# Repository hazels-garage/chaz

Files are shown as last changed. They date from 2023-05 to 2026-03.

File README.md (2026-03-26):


<a href="https://discord.gg/jP6hvgNN8r">
  
</a>

# Chaz

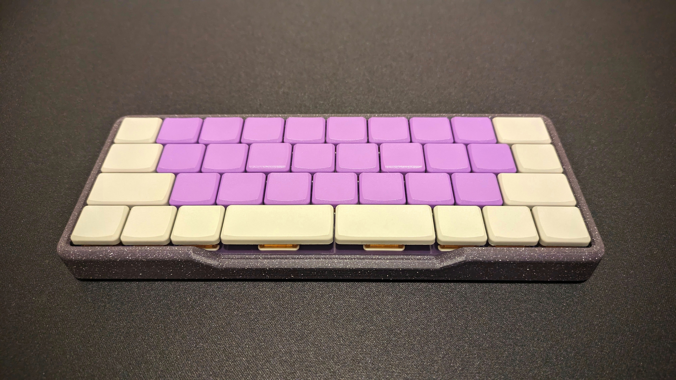
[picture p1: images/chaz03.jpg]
Chaz

Low Profile, Choc Spaced QAZ-alike

## Features
* QAZ Layout
* Choc Spaced
* Integrated STM32F702 microcontroller
* [Open Source](/source)

## Materials
* 1x Chaz PCB & Switchplate - [Buy](https://shop.hazel.cc/products/chaz-v03) - [Source](/source)
* 2x 2U Kailh Choc Stabalizers
* 37x Kailh Choc v1 Switches
* 37x Keycaps
  * 31x 1u 
  * 2x 1.25u
  * 1x 1.75u
  * 1x 1.5u
  * 1x 2u
  * 1x 2.25u
* 1x [Case](case/)
* 6x M2x6 countersunk screws  

## Build Steps
* Insert switches into switchplate
  * **NOTE**: There are 3 switches rotated differently from the rest.  Check the PCB to make sure you've got the correct orientation
* [Insert stabalizers](https://docs.keeb.io/choc-stabs)
* Place switchplate with switches onto PCB and press all the switches into their homes.
* Solder Switches
* Insert into case
* Screw Case to PCB from the bottom

## Firmware
To get into DFU, hold the DFU button on the bottom of the PCB while plugging in USB.

* [QMK](https://github.com/hazels-garage/qmk_firmware/tree/hazel/chaz)
* [VIAL](firmware/hazel_chaz_v03_vial.bin)
* [ZMK](https://github.com/hazels-garage/zmk-chaz)

## Changelog
* v0.3 - Current STM32F072CBT6 
* v0.2 - Unreleased and Unverified RP2040 
* v0.1 - Previously released ProMicro 
* v0.0 - Unreleased, but Verified ProMicro 

## Credits
* tominabox1 and whydobearsxplod for the original QAZ
* sporkus for [Le Chiffre STM32](https://github.com/sporkus/le_chiffre_keyboard_stm32) that I used as reference.
* [Pete Johanson](https://github.com/petejohanson) for suggesting I try STM32F072CBT6

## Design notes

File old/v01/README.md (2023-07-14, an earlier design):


<a href="https://shop.hazel.cc/products/chaz">
 </a>
<a href="https://discord.gg/jP6hvgNN8r">
  
</a>

# Chaz
Low profile, choc spaced QAZ-alike

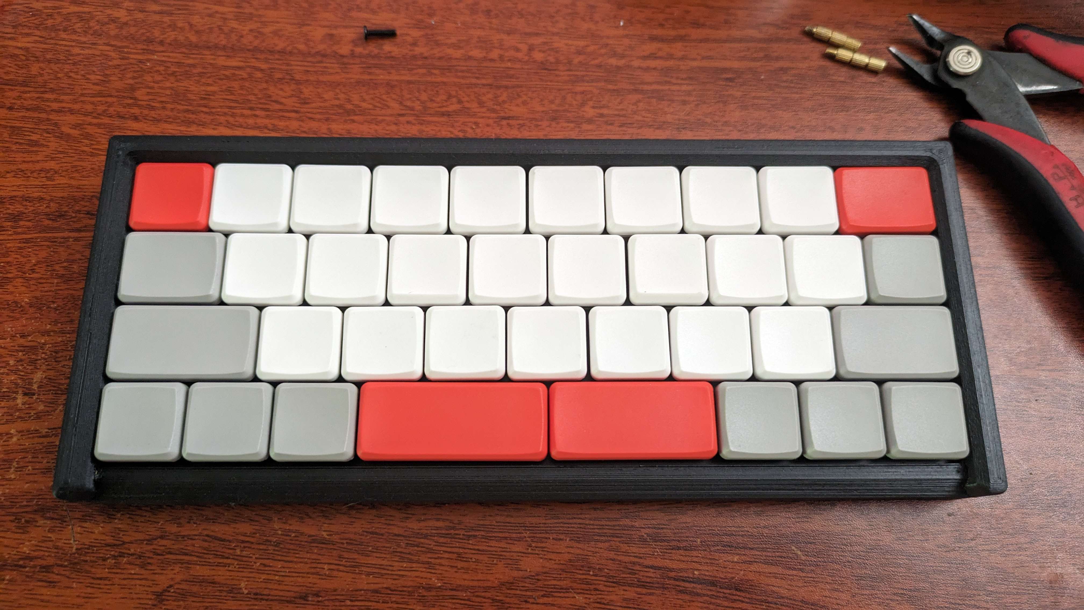
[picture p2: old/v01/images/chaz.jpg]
Chaz


# Features
* QAZ Layout
* Choc Spaced
* ProMicro Style Controllers
* Battery support
* [Open Source](source/)

# Materials
* 1x ProMicro Compatible Controller
* 1x [PH3.5 12P Socket](https://www.aliexpress.us/item/2251800435894905.html)
* 1x [PH3.5 7P Socket](https://www.aliexpress.us/item/2251800435894905.html)
* 37x Kailh Choc v1 switches
* 37x Keycaps
  * 31x 1u 
  * 2x 1.25u
  * 1x 1.75u
  * 1x 1.5u
  * 1x 2u
  * 1x 2.25u
* 37x SOD-123 1N4148 Diodes
* 1x [SKHLLCA010 Reset Button](https://www.aliexpress.us/item/3256804101901854.html)
* 1x [OS10201MA1QN1 Power Switch](https://www.digikey.com/en/products/detail/c-k/OS102011MA1QN1/1981430)  (optional)
* 2x [Kailh Choc 2u Stabalizers](https://www.aliexpress.us/item/2251832852867988.html)
* 4x 9mm M2 Standoffs
* 8x 4mm M2 Screws

# Build Guide
* Solder Diodes
* Solder Controller Headers
* Solder Reset Switch
* Solder Power Switch and Battery (Optional)
* Install Controller
* Flash [Firmware](FIRMWARE.md)
* Test matrix works 
  * use metal tweezers to short the connections for each switch on the PCB
* Insert Switches and Stabalizers into Switchplate
* Solder Switches to PCB (remove controller first)
* Attach Backplate to Switchplate with Standoffs and screws
* Done.

# Case Build Guide
* Print [Case](case/case.stl)
* Install 4x heatset inserts.
* secure switchplate to heatset inserts with Male/Female Brass Standoff
* 8mm-ish screw through Backplate into Brass Standoff

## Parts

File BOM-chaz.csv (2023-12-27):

Comment | Designator | Footprint | LCSC
DFU | BOOT0 | SW_SPST_TL3342 | C115351
4.7n | C_Shield1 | C_0402_1005Metric | C1538
10uF | C8 | C_0603_1608Metric | C19702
USB_C | J1 | Molex-216990_GCT-USB45xx_HRO-TYPE-C-31-M-13x | C223906
27R | R3,R4 | R_0603_1608Metric | C25190
10k | R5 | R_0402_1005Metric | C25744
5.1k | R1,R2 | R_0402_1005Metric | C25905
1M | R_Shield1 | R_0402_1005Metric | C26083
MountingHole | H1,H2,H3,H4,H5,H6 | MountingHole_M2_Pad_NonPTH_TopOnly | C2916384
100nF | C3,C4,C5,C6,C7,C9 | C_0402_1005Metric | C307331
1uF | C1,C2 | C_0402_1005Metric | C52923
XC6206 | U3 | SOT-23 | C5446
500mA | F1 | Fuse_1206_3216Metric | C70076
1N4148W | D1,D10,D11,D12,D13,D14,D15,D16,D17,D18,D19,D2,D20,D21,D22,D23,D24,D25,D26,D27,D28,D29,D3,D30,D31,D32,D33,D34,D35,D36,D37,D4,D5,D6,D7,D8,D9 | D_SOD-123 | C81598
STM32F072CBT6 | U1 | LQFP-48_7x7mm_P0.5mm | C81720
SRV05-4 | U2 | SOT-23-6-routable | C85364

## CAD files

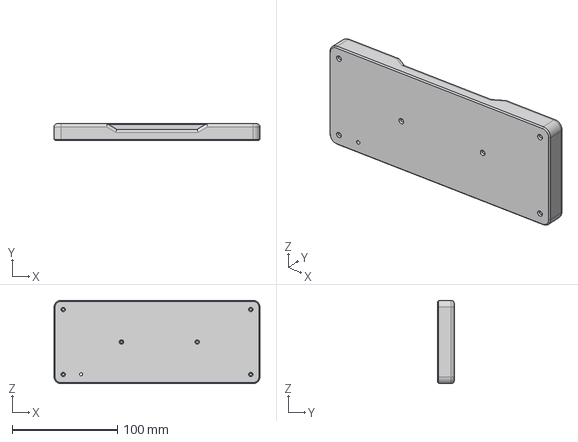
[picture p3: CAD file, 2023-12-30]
case/chaz-case.step
195.5 x 15.8 x 79.0 mm

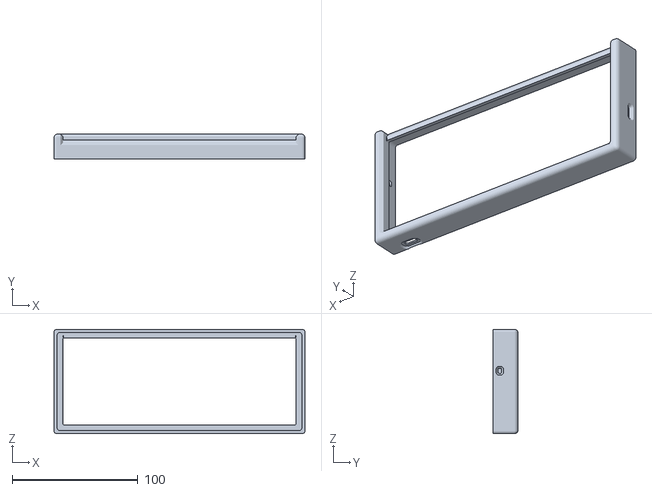
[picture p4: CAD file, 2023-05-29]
case/case.stl
199.5 x 20.0 x 83.0

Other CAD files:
case/chaz-case.3mf

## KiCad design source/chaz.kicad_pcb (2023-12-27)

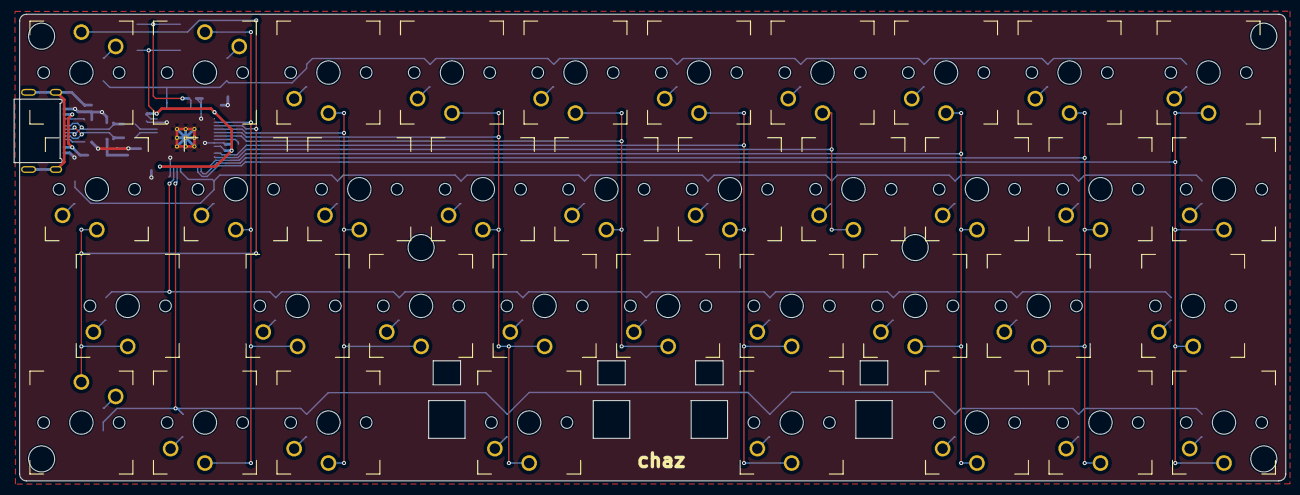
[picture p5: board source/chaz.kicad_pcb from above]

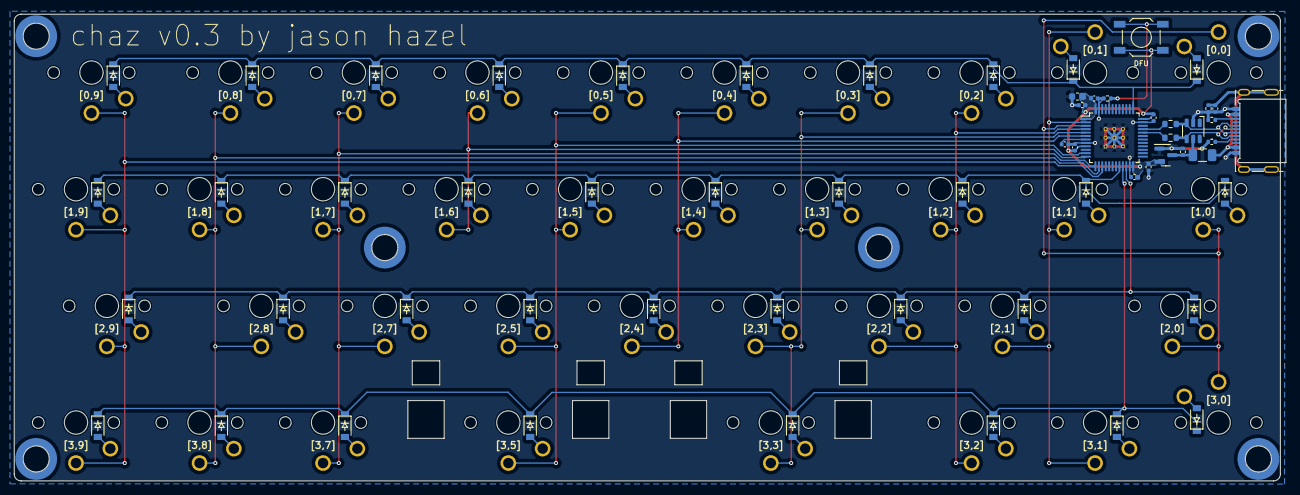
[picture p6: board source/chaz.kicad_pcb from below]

Board: 2 copper layers, 185.3 x 68.0 mm, 102 parts (65 on the bottom side), 64 nets.

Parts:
BOOT0: DFU; SW_SPST_TL3342
C1, C2: 1uF; C_0402_1005Metric
C3, C4, C5, C6, C7, C9: 100nF; C_0402_1005Metric
C8: 10uF; C_0603_1608Metric
C_Shield1: 4.7n; C_0402_1005Metric
D1, D2, D3, D4, D5, D6, D7, D8, D9, D10, D11, D12, D13, D14, D15, D16, D17, D18, D19, D20, D21, D22, D23, D24, D25, D26, D27, D28, D29, D30, D31, D32, D33, D34, D35, D36, D37: 1N4148W; D_SOD-123
F1: 500mA; Fuse_1206_3216Metric
H1, H2, H3, H4, H5, H6: MountingHole; MountingHole_M2_Pad_NonPTH_TopOnly
J1: USB_C; Molex-216990_GCT-USB45xx_HRO-TYPE-C-31-M-13x
R1, R2: 5.1k; R_0402_1005Metric
R3, R4: 27R; R_0603_1608Metric
R5: 10k; R_0402_1005Metric
R_Shield1: 1M; R_0402_1005Metric
SW1: [3,0]; choc-1u-millmax
SW2: [3,1]; choc-1u-millmax
SW3: [3,2]; choc-1u-millmax
SW4: [3,3]; Choc-2.25u-millmax
SW5: [3,5]; Choc-2u-millmax
SW6: [3,7]; choc-1u-millmax
SW7: [3,8]; choc-1u-millmax
SW8: [3,9]; choc-1u-millmax
SW9: [2,0]; Choc-1.75u-millmax
SW10: [2,1]; choc-1u-millmax
SW11: [2,2]; choc-1u-millmax
SW12: [2,3]; choc-1u-millmax
SW13: [2,4]; choc-1u-millmax
SW14: [2,5]; choc-1u-millmax
SW15: [2,7]; choc-1u-millmax
SW16: [2,8]; choc-1u-millmax
SW17: [2,9]; Choc-1.5u-millmax
SW18: [1,0]; Choc-1.25u-millmax
SW19: [1,1]; choc-1u-millmax
SW20: [1,2]; choc-1u-millmax
SW21: [1,3]; choc-1u-millmax
SW22: [1,4]; choc-1u-millmax
SW23: [1,5]; choc-1u-millmax
SW24: [1,6]; choc-1u-millmax
SW25: [1,7]; choc-1u-millmax
SW26: [1,8]; choc-1u-millmax
SW27: [1,9]; choc-1u-millmax
SW28: [0,0]; choc-1u-millmax
SW29: [0,1]; choc-1u-millmax
SW30: [0,2]; choc-1u-millmax
SW31: [0,3]; choc-1u-millmax
SW32: [0,4]; choc-1u-millmax
SW33: [0,5]; choc-1u-millmax
SW34: [0,6]; choc-1u-millmax
SW35: [0,7]; choc-1u-millmax
SW36: [0,8]; choc-1u-millmax
SW37: [0,9]; Choc-1.25u-millmax
U1: STM32F072CBT6; LQFP-48_7x7mm_P0.5mm
U2: SRV05-4; SOT-23-6-routable
U3: XC6206; SOT-23

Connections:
+3V3: BOOT0.1, C2.2, C3.1, C4.1, C5.1, C6.1, C7.1, C8.1, U1.1 (VBAT), U1.9 (VDDA), U1.24 (VDD), U1.36 (VDDIO2), U1.48 (VDD), U3.2 (VO)
+5V: C1.2, F1.2, U2.5 (VP), U3.3 (VI)
/stm32f072c/CC1: J1.A5 (CC1), R1.1
/stm32f072c/CC2: J1.B5 (CC2), R2.1
A1: SW5.2, SW14.2, SW23.2, SW33.2, U1.11 (PA1)
A2: SW24.2, SW34.2, U1.12 (PA2)
A3: SW6.2, SW15.2, SW25.2, SW35.2, U1.13 (PA3)
A4: SW7.2, SW16.2, SW26.2, SW36.2, U1.14 (PA4)
A5: SW8.2, SW17.2, SW27.2, SW37.2, U1.15 (PA5)
A14: D28.1 (K), D29.1 (K), D30.1 (K), D31.1 (K), D32.1 (K), D33.1 (K), D34.1 (K), D35.1 (K), D36.1 (K), D37.1 (K), U1.37 (PA14)
B2: D18.1 (K), D19.1 (K), D20.1 (K), D21.1 (K), D22.1 (K), D23.1 (K), D24.1 (K), D25.1 (K), D26.1 (K), D27.1 (K), U1.20 (PB2)
B10: D1.1 (K), D2.1 (K), D3.1 (K), D4.1 (K), D5.1 (K), D6.1 (K), D7.1 (K), D8.1 (K), U1.21 (PB10)
B11: D9.1 (K), D10.1 (K), D11.1 (K), D12.1 (K), D13.1 (K), D14.1 (K), D15.1 (K), D16.1 (K), D17.1 (K), U1.22 (PB11)
BOOT0: BOOT0.2, R5.1, U1.44 (BOOT0)
C13: SW2.2, SW10.2, SW19.2, SW29.2, U1.2 (PC13)
C14: SW1.2, SW9.2, SW18.2, SW28.2, U1.3 (PC14)
C15: SW3.2, SW11.2, SW20.2, SW30.2, U1.4 (PC15)
DBUS+: J1.A6 (D+), J1.B6 (D+), R3.1, U2.3 (IO2)
DBUS-: J1.A7 (D-), J1.B7 (D-), R4.1, U2.4 (IO3)
F0: SW4.2, SW12.2, SW21.2, SW31.2, U1.5 (PF0)
F1: SW13.2, SW22.2, SW32.2, U1.6 (PF1)
GND: C1.1, C2.1, C3.2, C4.2, C5.2, C6.2, C7.2, C8.2, C9.2, C_Shield1.1, J1.A1 (GND), J1.A12 (GND), J1.B1 (GND), J1.B12 (GND), R1.2, R2.2, R5.2, R_Shield1.2, U1.8 (VSSA), U1.23 (VSS), U1.35 (VSS), U1.47 (VSS), U2.2 (VN), U3.1 (GND)
GNDREF: C_Shield1.2, J1.S1 (SHIELD), R_Shield1.1
NRST: C9.1, U1.7 (NRST)
unnamed: D1.2 (A), SW1.1
unnamed: D2.2 (A), SW2.1
unnamed: D3.2 (A), SW3.1
unnamed: D4.2 (A), SW4.1
unnamed: D5.2 (A), SW5.1
unnamed: D6.2 (A), SW6.1
unnamed: D7.2 (A), SW7.1
unnamed: D8.2 (A), SW8.1
unnamed: D9.2 (A), SW9.1
unnamed: D10.2 (A), SW10.1
unnamed: D11.2 (A), SW11.1
unnamed: D12.2 (A), SW12.1
unnamed: D13.2 (A), SW13.1
unnamed: D14.2 (A), SW14.1
unnamed: D15.2 (A), SW15.1
unnamed: D16.2 (A), SW16.1
unnamed: D17.2 (A), SW17.1
unnamed: D18.2 (A), SW18.1
unnamed: D19.2 (A), SW19.1
unnamed: D20.2 (A), SW20.1
unnamed: D21.2 (A), SW21.1
unnamed: D22.2 (A), SW22.1
unnamed: D23.2 (A), SW23.1
unnamed: D24.2 (A), SW24.1
unnamed: D25.2 (A), SW25.1
unnamed: D26.2 (A), SW26.1
unnamed: D27.2 (A), SW27.1
unnamed: D28.2 (A), SW28.1
unnamed: D29.2 (A), SW29.1
unnamed: D30.2 (A), SW30.1
unnamed: D31.2 (A), SW31.1
unnamed: D32.2 (A), SW32.1
unnamed: D33.2 (A), SW33.1
unnamed: D34.2 (A), SW34.1
unnamed: D35.2 (A), SW35.1
unnamed: D36.2 (A), SW36.1
unnamed: D37.2 (A), SW37.1
unnamed: R4.2, U1.32 (PA11)
unnamed: R3.2, U1.33 (PA12)
VBUS: F1.1, J1.A4 (VBUS), J1.A9 (VBUS), J1.B4 (VBUS), J1.B9 (VBUS)

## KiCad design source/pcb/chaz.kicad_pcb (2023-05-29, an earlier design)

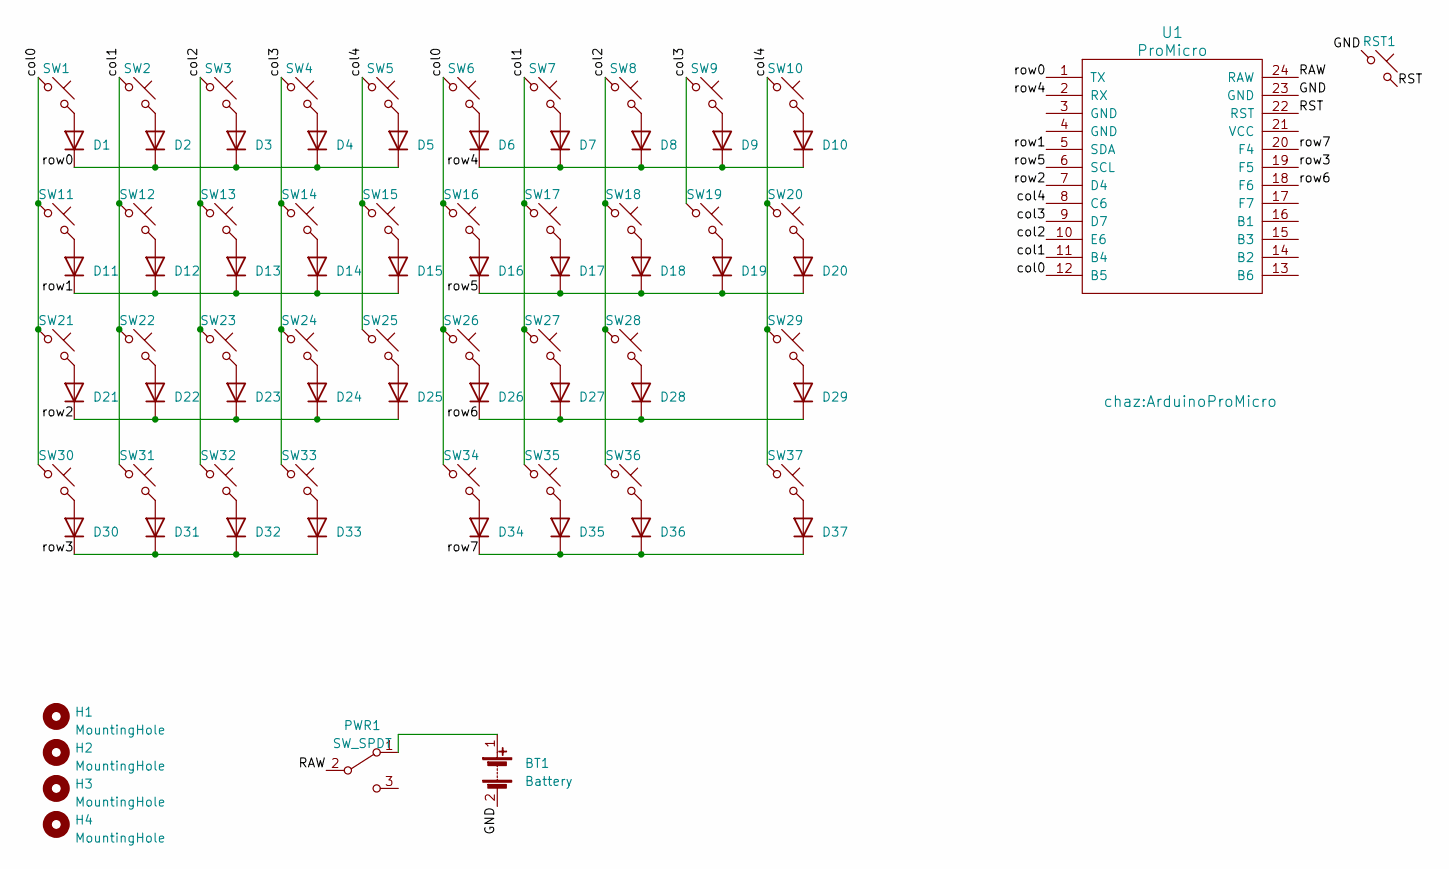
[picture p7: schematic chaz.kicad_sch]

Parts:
BT1: Battery; 3JST_BAT
D1, D2, D3, D4, D5, D6, D7, D8, D9, D10, D11, D12, D13, D14, D15, D16, D17, D18, D19, D20, D21, D22, D23, D24, D25, D26, D27, D28, D29, D30, D31, D32, D33, D34, D35, D36, D37: 1N4148W; D_SOD-123
H1, H2, H3, H4: MountingHole
PWR1: SW_SPDT; SW_CuK_OS102011MA1QN1_SPDT_Angled
RST1: SW_Push_45deg; SKHLLCA010
SW1, SW2, SW3, SW4, SW5, SW6, SW7, SW8, SW9, SW12, SW13, SW14, SW15, SW16, SW17, SW18, SW19, SW20, SW22, SW23, SW24, SW25, SW26, SW27, SW28, SW30, SW31, SW32, SW35, SW36, SW37: SW_Push_45deg; Choc-1u-solder
SW10, SW11: SW_Push_45deg; Choc-1.25u-solder
SW21: SW_Push_45deg; Choc-1.75u-solder
SW29: SW_Push_45deg; Choc-1.5u-solder
SW33: SW_Push_45deg; Choc-2.25u-solder
SW34: SW_Push_45deg; Choc-2u-solder
U1: ProMicro; ArduinoProMicro

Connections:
/GND: BT1.2 (-), RST1.1, U1.23 (GND)
/RAW: PWR1.2 (B), U1.24 (RAW)
/RST: RST1.2, U1.22 (RST)
/col0: SW1.1, SW6.1, SW11.1, SW16.1, SW21.1, SW26.1, SW30.1, SW34.1, U1.12 (B5)
/col1: SW2.1, SW7.1, SW12.1, SW17.1, SW22.1, SW27.1, SW31.1, SW35.1, U1.11 (B4)
/col2: SW3.1, SW8.1, SW13.1, SW18.1, SW23.1, SW28.1, SW32.1, SW36.1, U1.10 (E6)
/col3: SW4.1, SW9.1, SW14.1, SW19.1, SW24.1, SW33.1, U1.9 (D7)
/col4: SW5.1, SW10.1, SW15.1, SW20.1, SW25.1, SW29.1, SW37.1, U1.8 (C6)
/row0: D1.1 (K), D2.1 (K), D3.1 (K), D4.1 (K), D5.1 (K), U1.1 (TX)
/row1: D11.1 (K), D12.1 (K), D13.1 (K), D14.1 (K), D15.1 (K), U1.5 (SDA)
/row2: D21.1 (K), D22.1 (K), D23.1 (K), D24.1 (K), D25.1 (K), U1.7 (D4)
/row3: D30.1 (K), D31.1 (K), D32.1 (K), D33.1 (K), U1.19 (F5)
/row4: D6.1 (K), D7.1 (K), D8.1 (K), D9.1 (K), D10.1 (K), U1.2 (RX)
/row5: D16.1 (K), D17.1 (K), D18.1 (K), D19.1 (K), D20.1 (K), U1.6 (SCL)
/row6: D26.1 (K), D27.1 (K), D28.1 (K), D29.1 (K), U1.18 (F6)
/row7: D34.1 (K), D35.1 (K), D36.1 (K), D37.1 (K), U1.20 (F4)
unnamed: BT1.1 (+), PWR1.1 (A)
unnamed: D1.2 (A), SW1.2
unnamed: D2.2 (A), SW2.2
unnamed: D3.2 (A), SW3.2
unnamed: D4.2 (A), SW4.2
unnamed: D5.2 (A), SW5.2
unnamed: D6.2 (A), SW6.2
unnamed: D7.2 (A), SW7.2
unnamed: D8.2 (A), SW8.2
unnamed: D9.2 (A), SW9.2
unnamed: D10.2 (A), SW10.2
unnamed: D11.2 (A), SW11.2
unnamed: D12.2 (A), SW12.2
unnamed: D13.2 (A), SW13.2
unnamed: D14.2 (A), SW14.2
unnamed: D15.2 (A), SW15.2
unnamed: D16.2 (A), SW16.2
unnamed: D17.2 (A), SW17.2
unnamed: D18.2 (A), SW18.2
unnamed: D19.2 (A), SW19.2
unnamed: D20.2 (A), SW20.2
unnamed: D21.2 (A), SW21.2
unnamed: D22.2 (A), SW22.2
unnamed: D23.2 (A), SW23.2
unnamed: D24.2 (A), SW24.2
unnamed: D25.2 (A), SW25.2
unnamed: D26.2 (A), SW26.2
unnamed: D27.2 (A), SW27.2
unnamed: D28.2 (A), SW28.2
unnamed: D29.2 (A), SW29.2
unnamed: D30.2 (A), SW30.2
unnamed: D31.2 (A), SW31.2
unnamed: D32.2 (A), SW32.2
unnamed: D33.2 (A), SW33.2
unnamed: D34.2 (A), SW34.2
unnamed: D35.2 (A), SW35.2
unnamed: D36.2 (A), SW36.2
unnamed: D37.2 (A), SW37.2

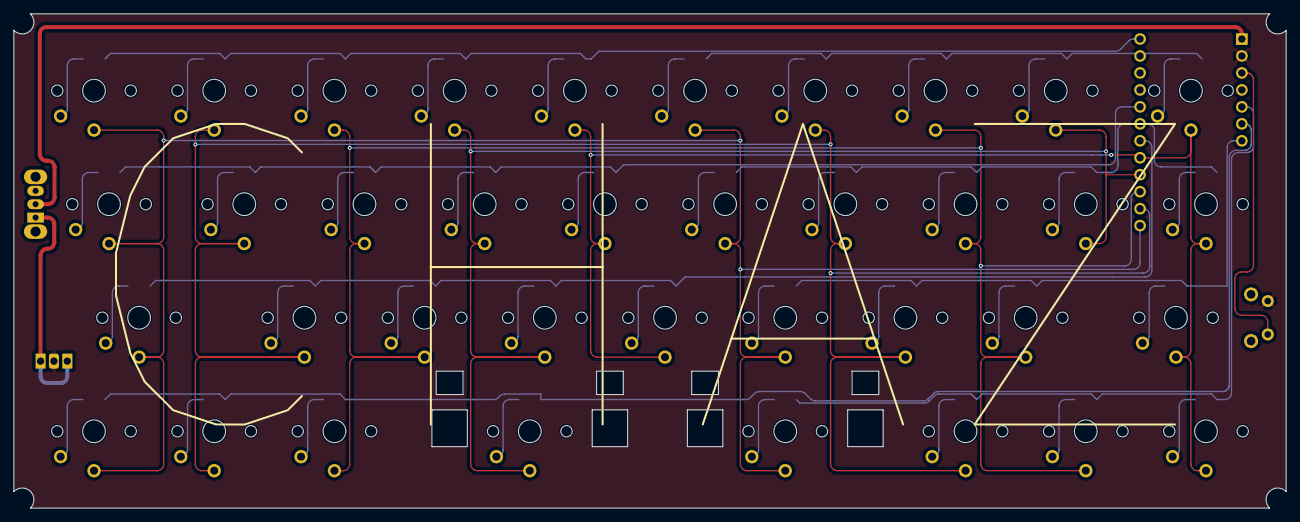
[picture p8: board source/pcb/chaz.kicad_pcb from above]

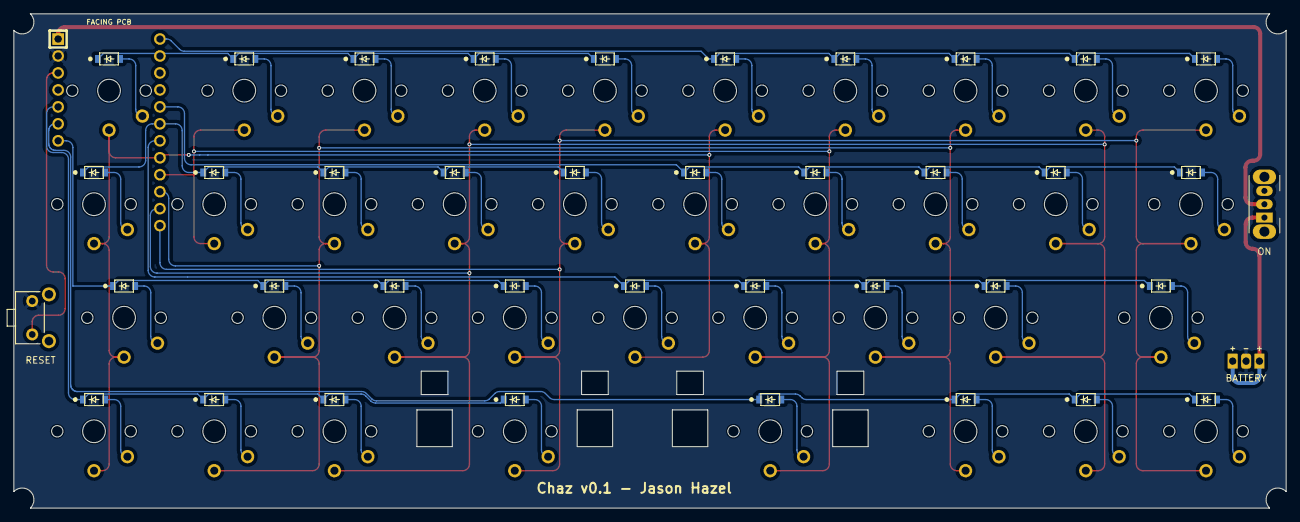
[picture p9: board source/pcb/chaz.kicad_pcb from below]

Board: 2 copper layers, 190.5 x 74.0 mm, 78 parts (39 on the bottom side), 54 nets.

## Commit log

2023-05-29 init chaz
    [case.stl, chaz.kicad_pcb, chaz.kicad_sch]
2023-12-14 adding v0.3
    [case.stl, chaz-case.3mf, chaz-case.step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]
2023-12-27 adding source
    [BOM-chaz.csv, chaz.kicad_pcb, chaz.kicad_sch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]
2023-12-30 fixed small gap in case that was causing printing artifacts
    [chaz-case.3mf, chaz-case.step]

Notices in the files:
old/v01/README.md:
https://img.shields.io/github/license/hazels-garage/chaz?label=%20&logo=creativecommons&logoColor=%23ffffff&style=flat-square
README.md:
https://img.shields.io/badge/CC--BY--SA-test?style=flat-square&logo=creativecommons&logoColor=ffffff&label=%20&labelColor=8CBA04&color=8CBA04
